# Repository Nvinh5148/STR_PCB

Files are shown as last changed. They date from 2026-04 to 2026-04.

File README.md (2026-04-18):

# STR_PCB

Custom PCB design for the low-level controller of the STR Robot autonomous vehicle platform.

## Overview

This repository contains the hardware design files for the custom controller board used in the STR Robot project. The board is designed to interface with the STM32-based firmware layer and provide the electrical bridge between the vehicle hardware and the ROS 2 autonomy stack.

This repository is part of the complete STR Robot simulation-to-reality system:
- custom PCB hardware
- STM32 micro-ROS firmware
- ROS 2 autonomy workspace
- real-world Ackermann robot deployment

## Board Preview



## Schematic Preview



**Schematic PDF:** [schematicf4.pdf](https://github.com/user-attachments/files/26848001/schematicf4.pdf)

## Repository Contents

- `f4_v2.kicad_sch` — KiCad schematic
- `f4_v2.kicad_pcb` — KiCad PCB layout
- `f4_v2.kicad_pro` — KiCad project file
- `Gerber_f4_v2/` — exported Gerber manufacturing files
- `Gerber_f4_v2.zip` — compressed Gerber package
- `f4_v2-backups/` — backup files

## Purpose

The board is designed as the low-level control hardware for the STR Robot platform. It supports the embedded controller responsible for:
- motor-related interfaces
- steering-related interfaces
- encoder and GPIO connections
- serial communication interfaces
- integration with the STM32 micro-ROS firmware layer

## System Role

This repository corresponds to the **hardware layer** of the full robot system:

`STR_PCB` → `microros_ws` → `ttbot_ws`

- **STR_PCB**: custom controller board
- **microros_ws**: STM32-based embedded firmware using micro-ROS
- **ttbot_ws**: high-level ROS 2 workspace for localization, planning, and navigation

## Hardware Interfaces

From the current board design, the PCB provides grouped connectors for:
- **GPIO**
- **ENCODER**
- **MOTOR**
- **UART / serial communication**
- power input / output terminals

## Toolchain

- KiCad for schematic and PCB design
- Standard Gerber export for PCB fabrication

## Manufacturing

To fabricate the board:
1. Open the project in KiCad
2. Review the schematic and PCB layout
3. Export or use the provided Gerber files in `Gerber_f4_v2/`
4. Submit the Gerber package to your PCB manufacturer

## Related Repositories

- Firmware: [`microros_ws`](https://github.com/Nvinh5148/microros_ws)
- ROS 2 autonomy stack: [`ttbot_ws`](https://github.com/Uyle-gif/ttbot_ws)

## Project Context

This board is part of the STR Robot simulation-to-reality development pipeline for an Ackermann-steered autonomous mobile robot.

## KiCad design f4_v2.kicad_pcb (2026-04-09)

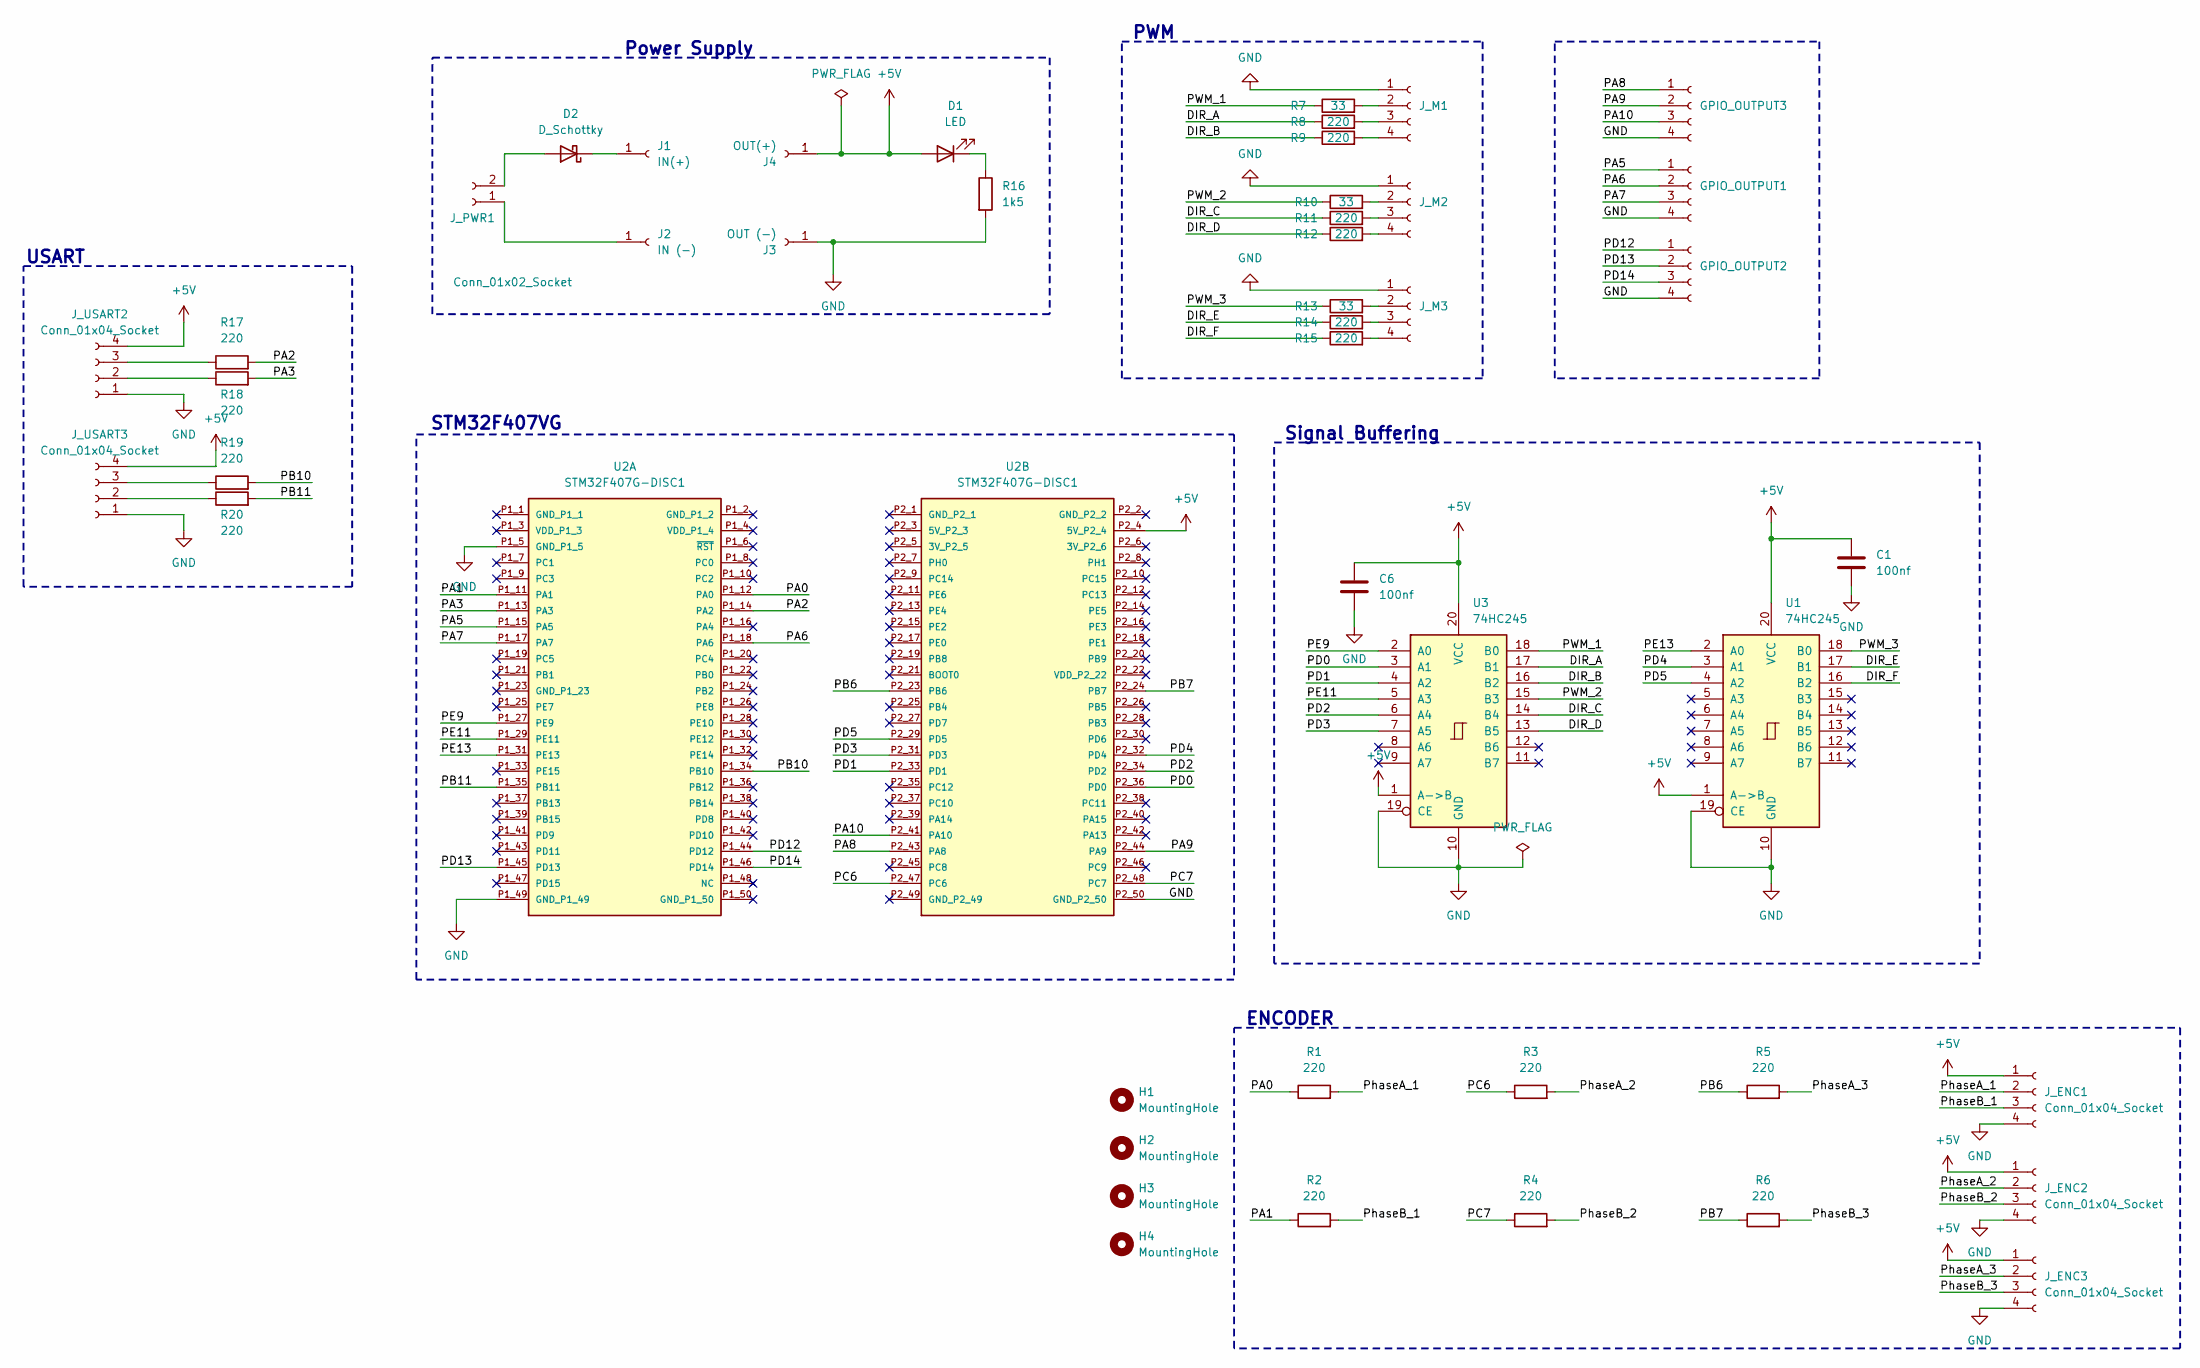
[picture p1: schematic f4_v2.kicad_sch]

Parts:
C1, C6: 100nf; C_0805_2012Metric
D1: LED; LED_0805_2012Metric
D2: D_Schottky; D_SMA
GPIO_OUTPUT1, GPIO_OUTPUT2, GPIO_OUTPUT3: JST_XH_B4B-XH-A_1x04_P2.50mm_Vertical
H1, H2, H3, H4: MountingHole; MountingHole_3.2mm_M3
J1: IN(+); PinHeader_1x01_P2.54mm_Vertical
J2: IN (-); PinHeader_1x01_P2.54mm_Vertical
J3: OUT (-); PinHeader_1x01_P2.54mm_Vertical
J4: OUT(+); PinHeader_1x01_P2.54mm_Vertical
J_ENC1, J_ENC2, J_ENC3: Conn_01x04_Socket; JST_XH_B4B-XH-A_1x04_P2.50mm_Vertical
J_M1, J_M2, J_M3: JST_XH_B4B-XH-A_1x04_P2.50mm_Vertical
J_PWR1: Conn_01x02_Socket; TerminalBlock_Phoenix_MKDS-1,5-2-5.08_1x02_P5.08mm_Horizont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
J_USART2, J_USART3: Conn_01x04_Socket; JST_XH_B4B-XH-A_1x04_P2.50mm_Vertical
R1, R2, R3, R4, R5, R6, R8, R9, R11, R12, R14, R15, R17, R18, R19, R20: 220; R_0805_2012Metric
R7, R10, R13: 33; R_0805_2012Metric
R16: 1k5; R_0805_2012Metric
U1, U3: 74HC245; TSSOP-20_4.4x6.5mm_P0.65mm
U2: STM32F407G-DISC1; MODULE_STM32F4DISCOVERY; PARTREV 7

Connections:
+5V: C1.1, C6.1, D1.2 (A), J4.1, J_ENC1.1, J_ENC2.1, J_ENC3.1, J_USART2.4, J_USART3.4, U1.1 (A->B), U1.20 (VCC), U2.P2_4 (5V_P2_4), U3.1 (A->B), U3.20 (VCC); also elsewhere on the board
/DIR_A: R8.1, U3.17 (B1)
/DIR_B: R9.1, U3.16 (B2)
/DIR_C: R11.1, U3.14 (B4)
/DIR_D: R12.1, U3.13 (B5)
/DIR_E: R14.1, U1.17 (B1)
/DIR_F: R15.1, U1.16 (B2)
/PA0: R1.1, U2.P1_12 (PA0)
/PA1: R2.1, U2.P1_11 (PA1)
/PA2: R17.2, U2.P1_14 (PA2)
/PA3: R18.2, U2.P1_13 (PA3)
/PA5: GPIO_OUTPUT1.1, U2.P1_15 (PA5)
/PA6: GPIO_OUTPUT1.2, U2.P1_18 (PA6)
/PA7: GPIO_OUTPUT1.3, U2.P1_17 (PA7)
/PA8: GPIO_OUTPUT3.1, U2.P2_43 (PA8)
/PA9: GPIO_OUTPUT3.2, U2.P2_44 (PA9)
/PA10: GPIO_OUTPUT3.3, U2.P2_41 (PA10)
/PB6: R5.1, U2.P2_23 (PB6)
/PB7: R6.1, U2.P2_24 (PB7)
/PB10: R19.2, U2.P1_34 (PB10)
/PB11: R20.2, U2.P1_35 (PB11)
/PC6: R3.1, U2.P2_47 (PC6)
/PC7: R4.1, U2.P2_48 (PC7)
/PD0: U2.P2_36 (PD0), U3.3 (A1)
/PD1: U2.P2_33 (PD1), U3.4 (A2)
/PD2: U2.P2_34 (PD2), U3.6 (A4)
/PD3: U2.P2_31 (PD3), U3.7 (A5)
/PD4: U1.3 (A1), U2.P2_32 (PD4)
/PD5: U1.4 (A2), U2.P2_29 (PD5)
/PD12: GPIO_OUTPUT2.1, U2.P1_44 (PD12)
/PD13: GPIO_OUTPUT2.2, U2.P1_45 (PD13)
/PD14: GPIO_OUTPUT2.3, U2.P1_46 (PD14)
/PE9: U2.P1_27 (PE9), U3.2 (A0)
/PE11: U2.P1_29 (PE11), U3.5 (A3)
/PE13: U1.2 (A0), U2.P1_31 (PE13)
/PWM_1: R7.1, U3.18 (B0)
/PWM_2: R10.1, U3.15 (B3)
/PWM_3: R13.1, U1.18 (B0)
/PhaseA_1: J_ENC1.2, R1.2
/PhaseA_2: J_ENC2.2, R3.2
/PhaseA_3: J_ENC3.2, R5.2
/PhaseB_1: J_ENC1.3, R2.2
/PhaseB_2: J_ENC2.3, R4.2
/PhaseB_3: J_ENC3.3, R6.2
GND: C1.2, C6.2, GPIO_OUTPUT1.4, GPIO_OUTPUT2.4, GPIO_OUTPUT3.4, J3.1, J_ENC1.4, J_ENC2.4, J_ENC3.4, J_M1.1, J_M2.1, J_M3.1, J_USART2.1, J_USART3.1, R16.2, U1.10 (GND), U1.19 (CE), U2.P1_5 (GND_P1_5), U2.P1_49 (GND_P1_49), U2.P2_50 (GND_P2_50), U3.10 (GND), U3.19 (CE); also elsewhere on the board
unnamed: D1.1 (K), R16.1
unnamed: D2.2 (A), J_PWR1.2
unnamed 47: D2.1 (K), J1.1; also elsewhere on the board
unnamed 48: J2.1, J_PWR1.1; also elsewhere on the board
unnamed: J_M1.2, R7.2
unnamed: J_M1.3, R8.2
unnamed: J_M1.4, R9.2
unnamed: J_M2.2, R10.2
unnamed: J_M2.3, R11.2
unnamed: J_M2.4, R12.2
unnamed: J_M3.2, R13.2
unnamed: J_M3.3, R14.2
unnamed: J_M3.4, R15.2
unnamed: J_USART2.2, R18.1
unnamed: J_USART2.3, R17.1
unnamed: J_USART3.2, R20.1
unnamed: J_USART3.3, R19.1

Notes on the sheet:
PWM
ENCODER
Signal Buffering
USART
STM32F407VG
Power Supply

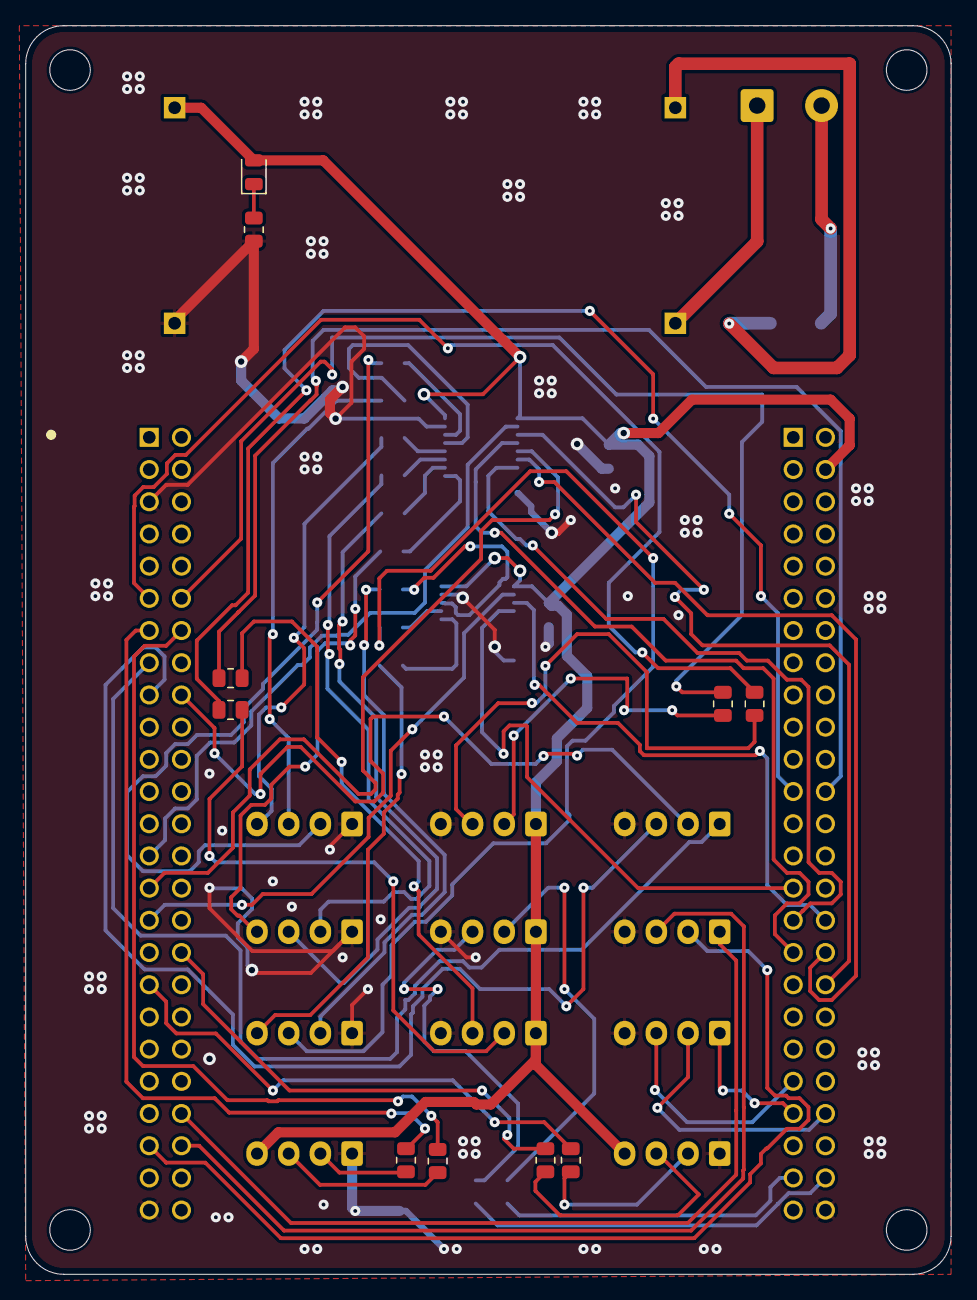
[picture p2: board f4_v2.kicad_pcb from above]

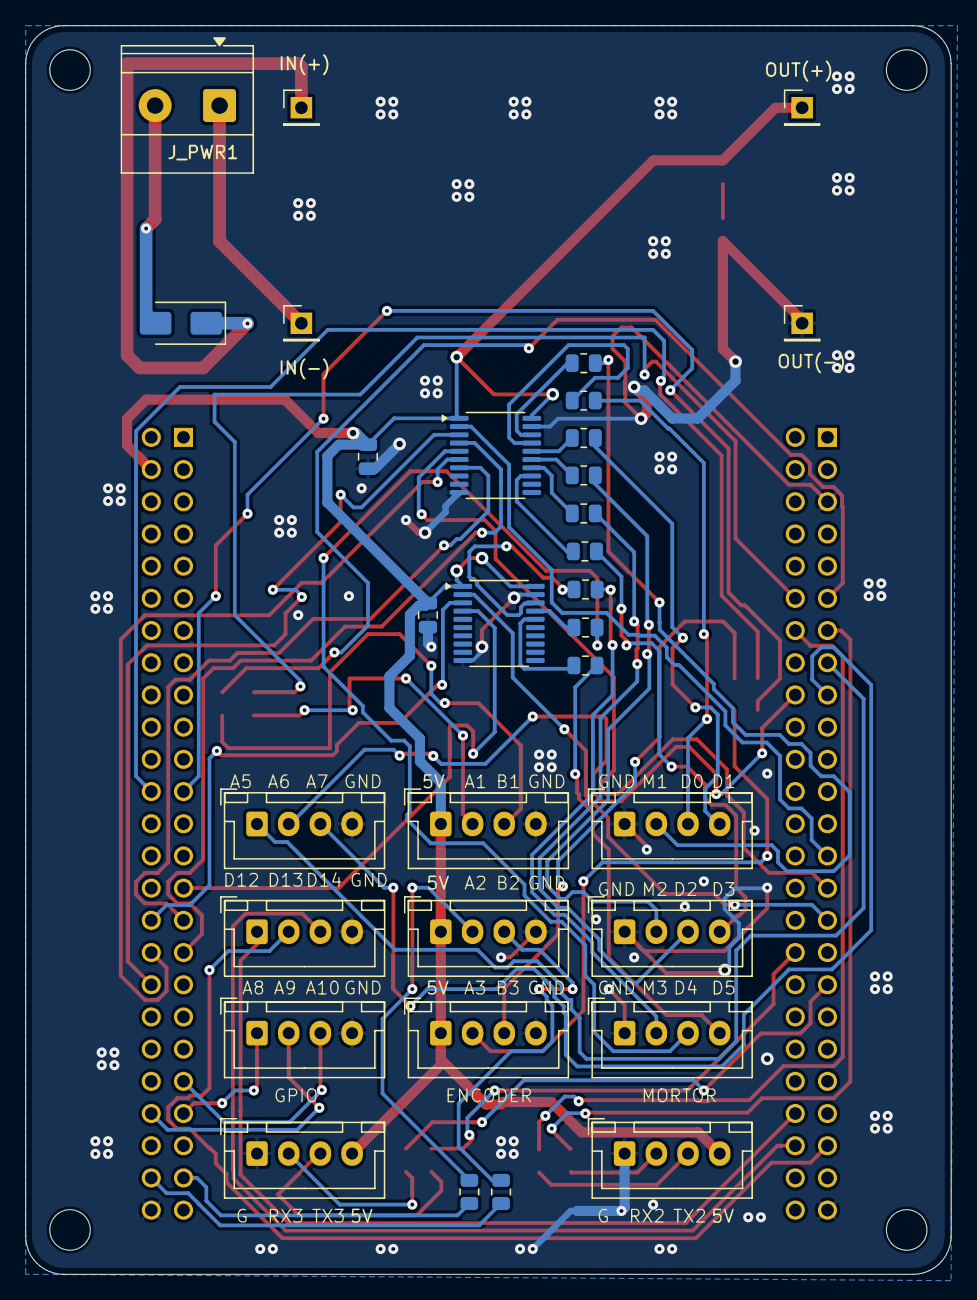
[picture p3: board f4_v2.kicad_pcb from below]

Board: 2 copper layers, 73.0 x 98.5 mm, 47 parts (32 on the bottom side), 62 nets.

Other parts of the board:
IN(+): IN(+); PinHeader_1x01_P2.54mm_Vertical
IN(-): IN (-); PinHeader_1x01_P2.54mm_Vertical
OUT(+): 5V; PinHeader_1x01_P2.54mm_Vertical
OUT(-): OUT (-); PinHeader_1x01_P2.54mm_Vertical

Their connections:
+5V: OUT(+).1; also elsewhere on the board
GND: OUT(-).1; also elsewhere on the board
unnamed 47: IN(+).1; also elsewhere on the board
unnamed 48: IN(-).1; also elsewhere on the board
